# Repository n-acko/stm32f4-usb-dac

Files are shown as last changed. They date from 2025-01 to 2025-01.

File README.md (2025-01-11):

STM32F401 USB Audio Stereo DAC

STM32F401RCT6 based PCB with PCM1780 DAC and DRV602 line driver.
Hardware folder contains Kicad project and manufacturing files for PCB.
Software folder contains STM32CudeIDE project for firmware.
Board supports 16/24bit audio depth and 44.1/48/96KHz audio frequency.

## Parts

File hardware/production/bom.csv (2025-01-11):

Designator | Footprint | Quantity | Value | LCSC Part #
C1, C12, C2, C22, C27, C29, C3, C4, C5 | 0402 | 9 | 100n | C77020
C10, C9 | CP_Elec_4x5.4 | 2 | 4.7u | C72511
C11, C33 | 0402 | 2 | 10n | C1524
C13, C23, C28, C32, C6 | 0805 | 5 | 10u | C15850
C14, C19 | 0402 | 2 | 100p | C327198
C15, C17 | 0402 | 2 | 680p | C782153
C16, C18 | CP_Elec_3x5.4 | 2 | 10u | C250999
C20, C25, C26 | 0805 | 3 | 1u | C215803
C21, C24 | 0402 | 2 | 33p | C107005
C30, C31 | 0603 | 2 | 1u | C15849
C7, C8 | 0402 | 2 | 20p | C182483
FB1, FB2 | 0603 | 2 | 220R | C80165
J1 | USB_C_Receptacle_G-Switch_GT-USB-7010ASV | 1 | USB_C_Receptacle_USB2.0_16P | C2988369
J2 | PinHeader_1x04_P2.54mm_Vertical | 1 | Conn_01x04_Pin | C7501582
J5 | XDJK-0271-1650 | 1 | Conn_Coaxial_x2 | C7527522
R1, R2 | 0603 | 2 | 5k1 | C844933
R10, R14 | 0402 | 2 | 28k | C2998150
R11, R12 | 0402 | 2 | 14k | C226789
R13, R9 | 0402 | 2 | 4k53 | C416543
R15, R16 | 0603 | 2 | 47 | C114623
R17 | 0603 | 1 | 10k | C844918
RV1 | Potentiometer_Alps_RK163_Single_Horizontal | 1 | R_Potentiometer | C3007973
SW1 | JS102011JCQN | 1 | SW_SPDT | C221659
U1 | LQFP-64_10x10mm_P0.5mm | 1 | STM32F401RCT6 | C74524
U2 | SSOP-16_3.9x4.9mm_P0.635mm | 1 | PCM1780 | C130014
U4 | SOT-23-6 | 1 | USBLC6-2SC6 | C2827654
U5 | TSSOP-14_4.4x5mm_P0.65mm | 1 | DRV602PWR | C129432
U6 | SOT-23-5 | 1 | 74AHC1G02 | C7463
U7 | SOT-23-5 | 1 | SPX3819M5-L-3-3 | C9055
Y1 | Crystal_SMD_3225-4Pin_3.2x2.5mm | 1 | 24MHz | C7466181

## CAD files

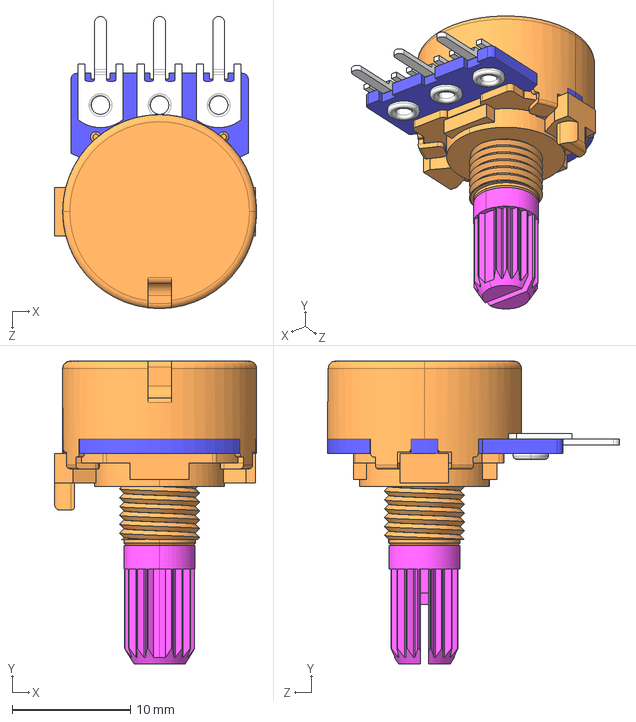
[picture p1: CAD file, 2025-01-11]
hardware/RK1631110U2A/RK1631110-K15-P.STEP
17.1 x 25.6 x 24.7 mm

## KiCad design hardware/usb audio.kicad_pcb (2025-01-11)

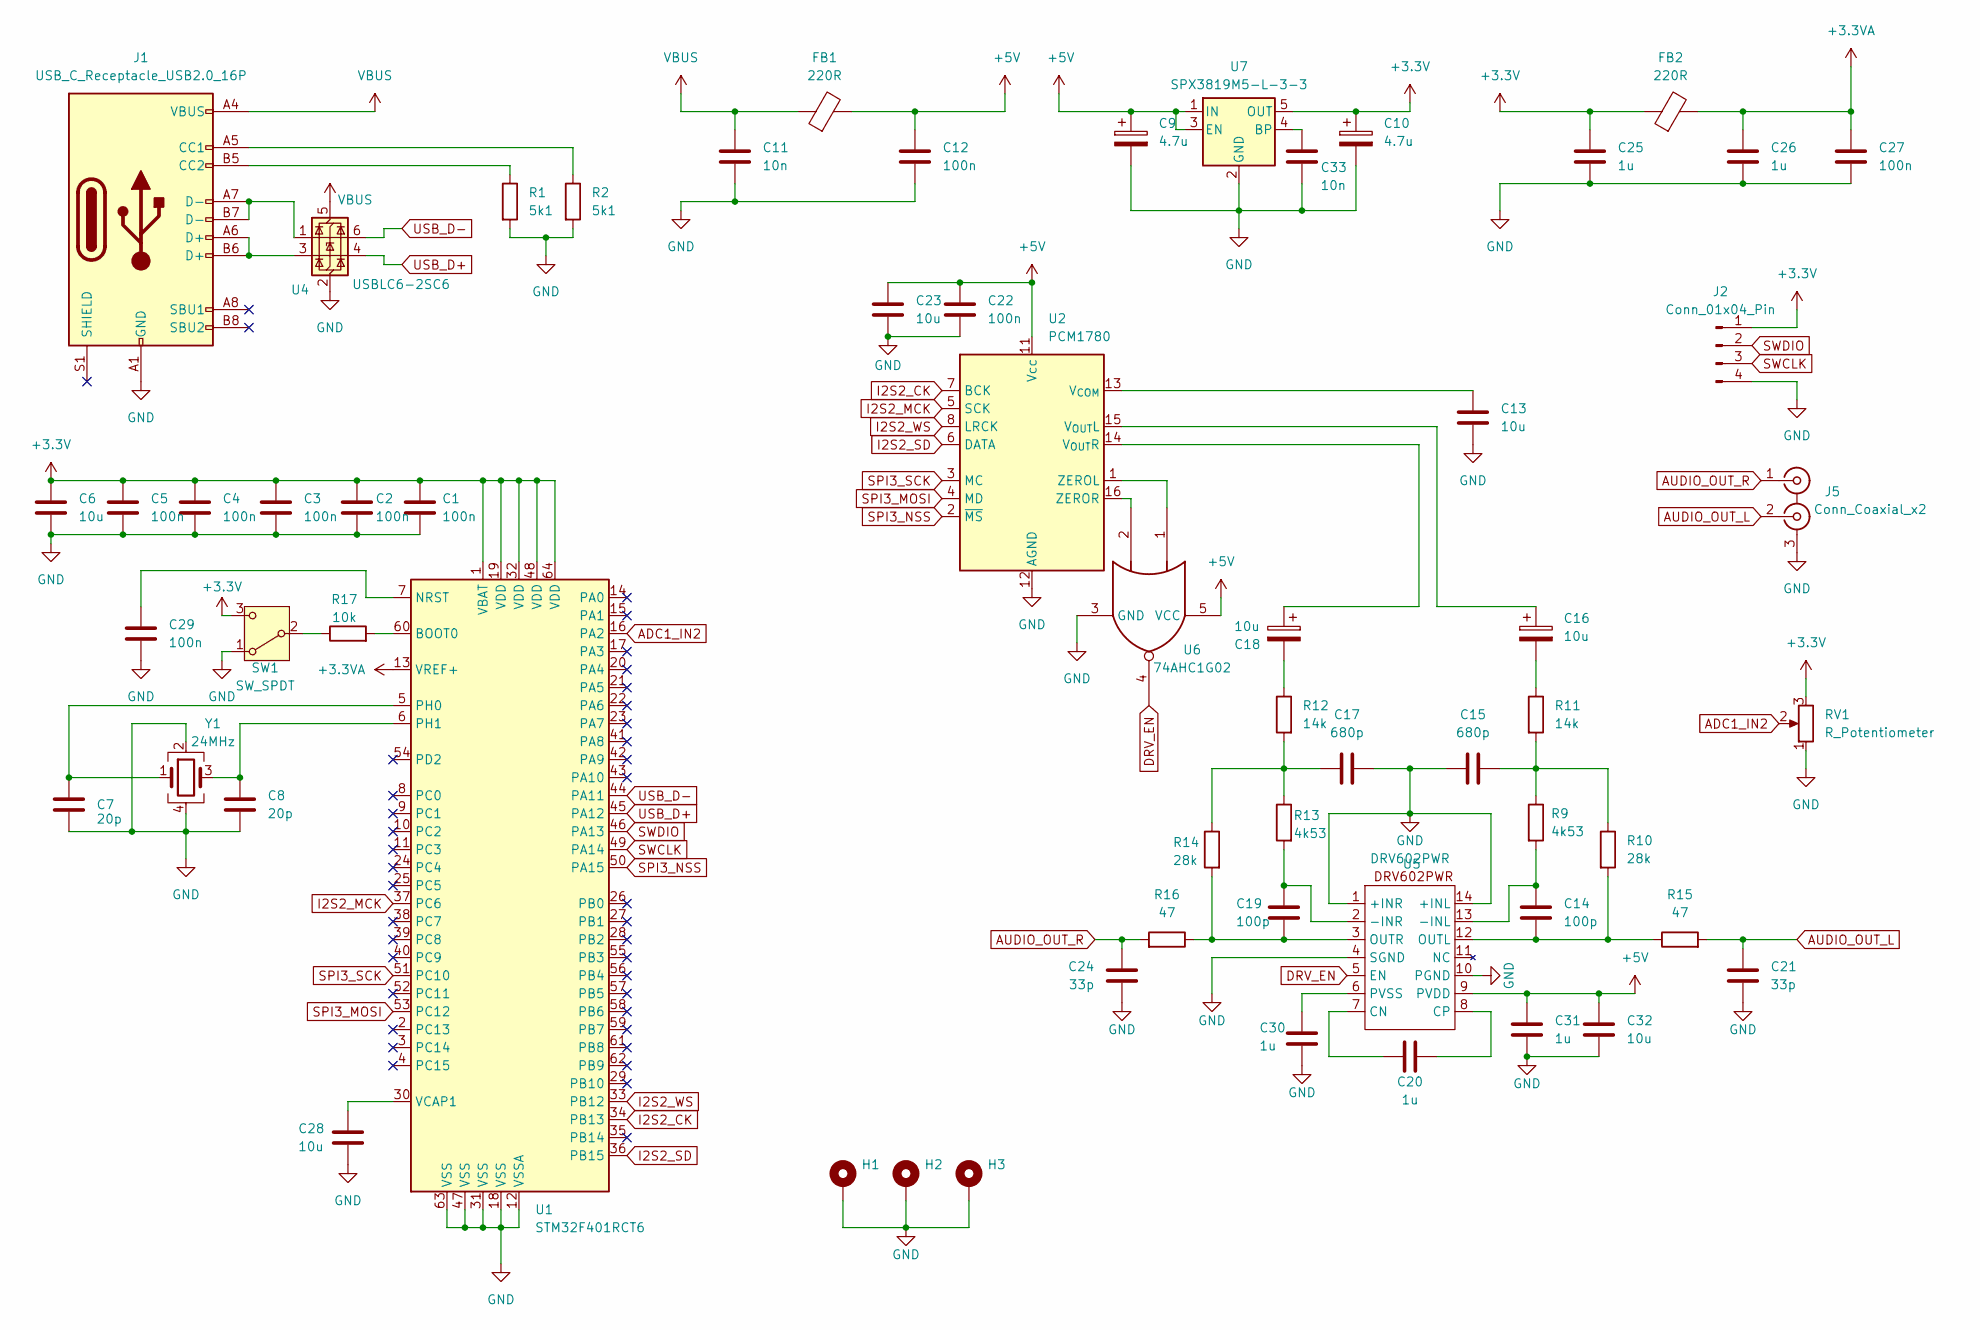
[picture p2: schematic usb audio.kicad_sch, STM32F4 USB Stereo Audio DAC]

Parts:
C1, C2, C3, C4, C5, C12, C22, C27, C29: 100n; C_0402_1005Metric
C6, C13, C23, C28, C32: 10u; C_0805_2012Metric
C7, C8: 20p; C_0402_1005Metric
C9, C10: 4.7u; CP_Elec_4x5.4
C11, C33: 10n; C_0402_1005Metric
C14, C19: 100p; C_0402_1005Metric
C15, C17: 680p; C_0402_1005Metric
C16, C18: 10u; CP_Elec_3x5.4
C20, C25, C26: 1u; C_0805_2012Metric
C21, C24: 33p; C_0402_1005Metric
C30, C31: 1u; C_0603_1608Metric
FB1, FB2: 220R; L_0603_1608Metric
H1, H2, H3: MountingHole_Pad; MountingHole_2.2mm_M2_Pad_Via
J1: USB_C_Receptacle_USB2.0_16P; USB_C_Receptacle_G-Switch_GT-USB-7010ASV
J2: Conn_01x04_Pin; PinHeader_1x04_P2.54mm_Vertical
J5: Conn_Coaxial_x2; XDJK-0271-1650
R1, R2: 5k1; R_0603_1608Metric
R9, R13: 4k53; R_0402_1005Metric
R10, R14: 28k; R_0402_1005Metric
R11, R12: 14k; R_0402_1005Metric
R15, R16: 47; R_0603_1608Metric
R17: 10k; R_0603_1608Metric
RV1: R_Potentiometer; Potentiometer_Alps_RK163_Single_Horizontal
SW1: SW_SPDT; JS102011JCQN
U1: STM32F401RCT6; LQFP-64_10x10mm_P0.5mm
U2: PCM1780; SSOP-16_3.9x4.9mm_P0.635mm
U4: USBLC6-2SC6; SOT-23-6
U5: DRV602PWR; TSSOP-14_4.4x5mm_P0.65mm
U6: 74AHC1G02; SOT-23-5
U7: SPX3819M5-L-3-3; SOT-23-5
Y1: 24MHz; Crystal_SMD_3225-4Pin_3.2x2.5mm

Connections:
+3.3V: C1.1, C2.1, C3.1, C4.1, C5.1, C6.1, C10.1, C25.1, FB2.1, J2.1, RV1.3, SW1.3 (C), U1.1 (VBAT), U1.19 (VDD), U1.32 (VDD), U1.48 (VDD), U1.64 (VDD), U7.5 (OUT)
+3.3VA: C26.1, C27.1, FB2.2, U1.13 (VREF+)
+5V: C9.1, C12.1, C22.1, C23.1, C31.1, C32.1, FB1.2, U2.11 (Vcc), U5.9 (PVDD), U6.5 (VCC), U7.1 (IN), U7.3 (EN)
ADC1_IN2: RV1.2, U1.16 (PA2)
AUDIO_OUT_L: C21.1, J5.2 (IN2), R15.2
AUDIO_OUT_R: C24.1, J5.1 (IN1), R16.2
DRV_EN: U5.5 (EN), U6.4
GND: C1.2, C2.2, C3.2, C4.2, C5.2, C6.2, C7.2, C8.2, C9.2, C10.2, C11.2, C12.2, C13.2, C15.1, C17.1, C21.2, C22.2, C23.2, C24.2, C25.2, C26.2, C27.2, C28.2, C29.2, C30.2, C31.2, C32.2, C33.2, H1.1, H2.1, H3.1, J1.A1 (GND), J1.A12 (GND), J1.B1 (GND), J1.B12 (GND), J2.4, J5.3 (EXT), R1.2, R2.2, RV1.1, SW1.1 (A), U1.12 (VSSA), U1.18 (VSS), U1.31 (VSS), U1.47 (VSS), U1.63 (VSS), U2.12 (AGND), U4.2 (GND), U5.1 (+INR), U5.4 (SGND), U5.10 (PGND), U5.14 (+INL), U6.3 (GND), U7.2 (GND), Y1.2, Y1.4
I2S2_CK: U1.34 (PB13), U2.7 (BCK)
I2S2_MCK: U1.37 (PC6), U2.5 (SCK)
I2S2_SD: U1.36 (PB15), U2.6 (DATA)
I2S2_WS: U1.33 (PB12), U2.8 (LRCK)
unnamed: C15.2, R9.1, R10.1, R11.2
unnamed: C16.2, R11.1
unnamed: C17.2, R12.2, R13.1, R14.1
unnamed: C18.2, R12.1
unnamed: J1.A5 (CC1), R2.1
unnamed: J1.B5 (CC2), R1.1
unnamed: J1.A6 (D+), J1.B6 (D+), U4.3 (I/O2)
unnamed: J1.A7 (D-), J1.B7 (D-), U4.1 (I/O1)
unnamed: R17.1, SW1.2 (B)
unnamed: R17.2, U1.60 (BOOT0)
unnamed: C29.1, U1.7 (NRST)
unnamed: C7.1, U1.5 (PH0), Y1.1
unnamed: C8.1, U1.6 (PH1), Y1.3
unnamed: C28.1, U1.30 (VCAP1)
unnamed: C13.1, U2.13 (V_{COM})
unnamed: C16.1, U2.15 (V_{OUT}L)
unnamed: C18.1, U2.14 (V_{OUT}R)
unnamed: U2.1 (ZEROL), U6.1
unnamed: U2.16 (ZEROR), U6.2
unnamed: C14.1, R9.2, U5.13 (-INL)
unnamed: C19.1, R13.2, U5.2 (-INR)
unnamed: C20.2, U5.7 (CN)
unnamed: C20.1, U5.8 (CP)
unnamed: C14.2, R10.2, R15.1, U5.12 (OUTL)
unnamed: C19.2, R14.2, R16.1, U5.3 (OUTR)
unnamed: C30.1, U5.6 (PVSS)
unnamed: C33.1, U7.4 (BP)
SPI3_MOSI: U1.53 (PC12), U2.4 (MD)
SPI3_NSS: U1.50 (PA15), U2.2 (~MS)
SPI3_SCK: U1.51 (PC10), U2.3 (MC)
SWCLK: J2.3, U1.49 (PA14)
SWDIO: J2.2, U1.46 (PA13)
USB_D+: U1.45 (PA12), U4.4 (I/O2)
USB_D-: U1.44 (PA11), U4.6 (I/O1)
VBUS: C11.1, FB1.1, J1.A4 (VBUS), J1.A9 (VBUS), J1.B4 (VBUS), J1.B9 (VBUS), U4.5 (VBUS)

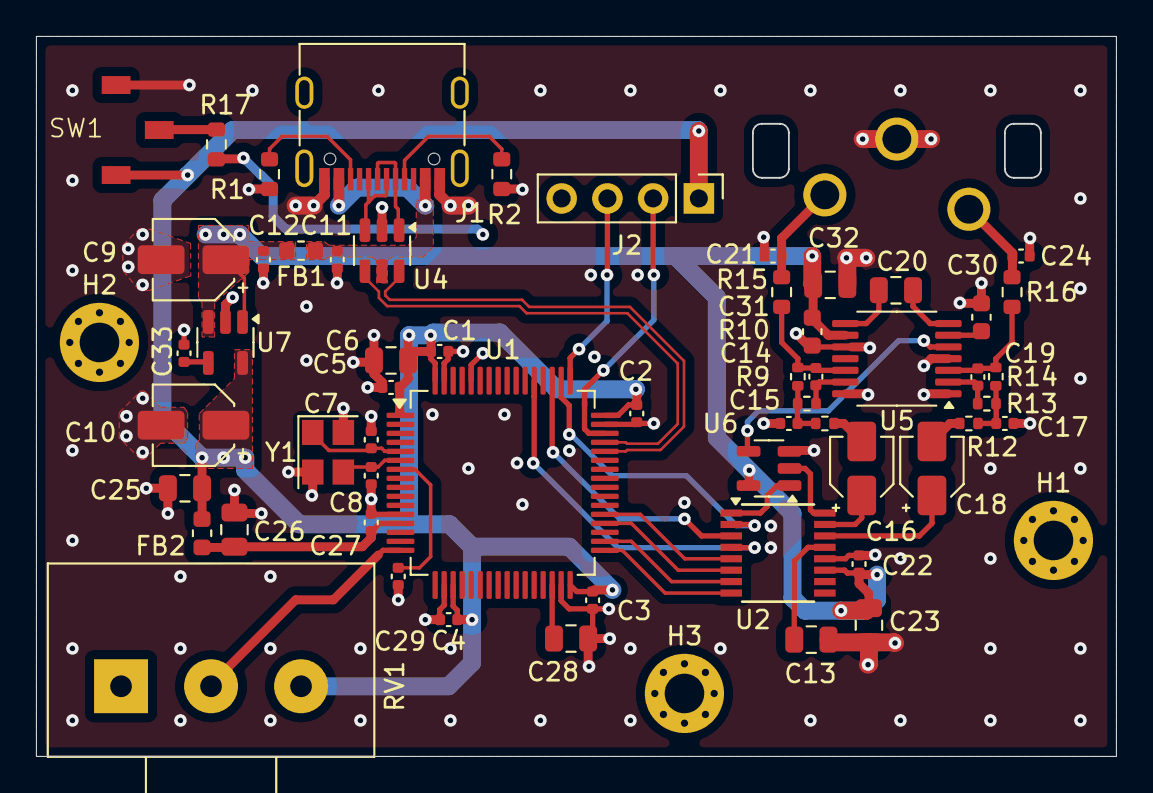
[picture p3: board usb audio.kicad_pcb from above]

Board: 4 copper layers, 60.0 x 40.0 mm, 61 parts (0 on the bottom side), 47 nets.

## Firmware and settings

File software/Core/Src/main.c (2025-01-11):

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
/* Includes ------------------------------------------------------------------*/
#include "main.h"
#include "usb_device.h"

/* USER CODE BEGIN PD */
#define BUFFER_SIZE 480
/* USER CODE END PD */

ADC_HandleTypeDef hadc1;

I2S_HandleTypeDef hi2s2;
DMA_HandleTypeDef hdma_spi2_tx;

/* USER CODE BEGIN PV */
uint32_t buffer[BUFFER_SIZE] = {0};
uint8_t activeBuffHalf = 0;
uint8_t readyForData = 0;
uint8_t mute = 0;
uint8_t lastMute = 0;
uint8_t updateFreq = 0;
uint32_t freq = 48000U, lastFreq = 48000U;
uint8_t bitDepth = 16U, lastBitDepth = 16U;
uint16_t adcVal = 0;
int16_t vol = -1;
uint32_t mainSN = 344U, mainSR = 2U;
/* USER CODE END PV */

void SystemClock_Config(void);
static void MX_GPIO_Init(void);
static void MX_DMA_Init(void);
static void MX_I2S2_Init(void);
static void MX_ADC1_Init(void);
/* USER CODE BEGIN PFP */

uint8_t DAC_WRITE(uint8_t addr, uint8_t data);
void DAC_INIT();
void customSPI(uint16_t data);

/* USER CODE END PFP */

/* USER CODE BEGIN 0 */
void HAL_I2S_TxCpltCallback(I2S_HandleTypeDef* hi2s){
	activeBuffHalf = 0;
	updateBuffer();
}

void HAL_I2S_TxHalfCpltCallback(I2S_HandleTypeDef *hi2s){
	activeBuffHalf = 1;
	updateBuffer();
}
/* USER CODE END 0 */

/**
  * @brief  The application entry point.
  * @retval int
  */
int main(void)
{

  /* MCU Configuration--------------------------------------------------------*/

  /* Reset of all peripherals, Initializes the Flash interface and the Systick. */
  HAL_Init();

  /* USER CODE BEGIN Init */
  HAL_Delay(1000);
  /* USER CODE END Init */

  /* Configure the system clock */
  SystemClock_Config();

  /* Initialize all configured peripherals */
  MX_GPIO_Init();
  MX_DMA_Init();
  MX_I2S2_Init();
  MX_USB_DEVICE_Init();
  MX_ADC1_Init();
  /* USER CODE BEGIN 2 */
  getInfo(buffer, BUFFER_SIZE, &activeBuffHalf);
  getMute(&mute);
  getFreqPoint(&freq, &updateFreq, &bitDepth);
  HAL_StatusTypeDef status = HAL_I2S_Transmit_DMA(&hi2s2, (uint16_t*)buffer, BUFFER_SIZE);
  DAC_INIT();
  HAL_ADC_Start(&hadc1);
  /* USER CODE END 2 */

  /* Infinite loop */
  /* USER CODE BEGIN WHILE */
  while (1)
  {
    /* USER CODE END WHILE */

    /* USER CODE BEGIN 3 */
	  if(updateFreq){
		  HAL_I2S_DMAStop(&hi2s2);
		  HAL_I2S_DeInit(&hi2s2);
		  HAL_I2S_MspDeInit(&hi2s2);
		  if(freq != lastFreq){
			  lastFreq = freq;
			  switch(freq){
			  case 44100U:
				  mainSN = 271U;
				  mainSR = 2U;
				  break;
			  default:
				  mainSN = 344U;
				  mainSR = 2U;
				  break;
			  }
			  hi2s2.Init.AudioFreq = freq;
		  }
		  if(bitDepth != lastBitDepth){
			  lastBitDepth = bitDepth;
			  switch(bitDepth){
			  case 16U:
				  hdma_spi2_tx.Init.MemDataAlignment = (uint32_t)(2U << 13);
				  hi2s2.Init.DataFormat = I2S_DATAFORMAT_16B_EXTENDED;
				  break;
			  case 24U:
				  hdma_spi2_tx.Init.MemDataAlignment = (uint32_t)(1U << 13);
				  hi2s2.Init.DataFormat = I2S_DATAFORMAT_24B;
				  break;
			  }
		  }
		  MX_I2S2_Init();
		  HAL_I2S_Transmit_DMA(&hi2s2, (uint16_t*)buffer, BUFFER_SIZE);
		  updateFreq = 0;
	  }

	  if(mute && !lastMute){
		  DAC_WRITE(18, 3);
		  lastMute = 1;
	  }
	  if(lastMute && !mute){
		  DAC_WRITE(18, 0);
		  lastMute = 0;
	  }

	  HAL_ADC_Start(&hadc1);
	  HAL_ADC_PollForConversion(&hadc1, 100);
	  adcVal = HAL_ADC_GetValue(&hadc1);

	  if (vol == -1){
		  vol = adcVal >> 1;
		  DAC_WRITE(16, vol + 128);
		  DAC_WRITE(17, vol + 128);
	  }
	  else if((adcVal >> 1) != vol){
		  vol = adcVal >> 1;
		  DAC_WRITE(16, vol + 128);
		  DAC_WRITE(17, vol + 128);
	  }
  }
  /* USER CODE END 3 */
}

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
/* USER CODE BEGIN 4 */

uint8_t DAC_WRITE(uint8_t addr, uint8_t data){

	uint16_t buf = (addr << 8) + data;

	customSPI(buf);
	HAL_Delay(10);

	return 0;
}

void DAC_INIT(){

	DAC_WRITE(16, 127);
	DAC_WRITE(17, 127);
	DAC_WRITE(18, 0);
}

void customSPI(uint16_t data){

	for(int i = 0; i < 64; i++){
	HAL_GPIO_WritePin(CLOCK_GPIO_Port, CLOCK_Pin, 0);
	HAL_GPIO_WritePin(CLOCK_GPIO_Port, CLOCK_Pin, 1);
	}

	HAL_GPIO_WritePin(CLOCK_GPIO_Port, CLOCK_Pin, 0);
	HAL_GPIO_WritePin(NCS_GPIO_Port, NCS_Pin, 0);
	for(int i = 0; i < 16; i++){
		if(data & (1 << (15-i))){
			HAL_GPIO_WritePin(SDATA_GPIO_Port, SDATA_Pin, 1);
		}
		else{
			HAL_GPIO_WritePin(SDATA_GPIO_Port, SDATA_Pin, 0);
		}
		HAL_GPIO_WritePin(CLOCK_GPIO_Port, CLOCK_Pin, 1);
		HAL_GPIO_WritePin(CLOCK_GPIO_Port, CLOCK_Pin, 0);
	}
	HAL_GPIO_WritePin(NCS_GPIO_Port, NCS_Pin, 1);
	HAL_GPIO_WritePin(CLOCK_GPIO_Port, CLOCK_Pin, 1);

	for(int i = 0; i < 64; i++){
		HAL_GPIO_WritePin(CLOCK_GPIO_Port, CLOCK_Pin, 0);
		HAL_GPIO_WritePin(CLOCK_GPIO_Port, CLOCK_Pin, 1);
	}

}


void getPllValues(uint32_t* pllsn, uint32_t* pllsr){
	*pllsn = mainSN;
	*pllsr = mainSR;
}
/* USER CODE END 4 */
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


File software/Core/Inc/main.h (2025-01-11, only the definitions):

#define NCS_Pin GPIO_PIN_15
#define NCS_GPIO_Port GPIOA
#define CLOCK_Pin GPIO_PIN_10
#define CLOCK_GPIO_Port GPIOC
#define SDATA_Pin GPIO_PIN_12
#define SDATA_GPIO_Port GPIOC

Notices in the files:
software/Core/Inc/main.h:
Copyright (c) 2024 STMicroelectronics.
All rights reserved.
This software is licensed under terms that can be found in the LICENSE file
